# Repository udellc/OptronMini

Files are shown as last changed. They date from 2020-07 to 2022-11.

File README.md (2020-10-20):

# OptronMini
Repo for the Optron Mini

# Project Wiki:
https://github.com/udellc/OptronMini/wiki

# Folder Details
### BOM
Link to live spreadsheet of materials and links to products
### CAD
DXF: Laser Cutting File for Mini Frame
PCB: .sch and .brd files for Mini Circuit board
STL: 3D printer files
Archive: Old file dump for your enjoyment
### Code
Arduino code to download onto your Adafruit ItsyBitsy M4
### MaxMSP
Max8 apps tto use your Optron Mini!

# Getting Started
Please visit the Optron Project Wiki for setting up your Optron Mini!

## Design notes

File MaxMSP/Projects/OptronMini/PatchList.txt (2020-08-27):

--Input--
ModuleCore
GeneralViewer
Sensor
PositionVisualizer
SelectSD_Config
MidiIn
OSC_In
ArduinoIn
OptronMini
OptronZX
--Process--
ChordDegree
Concatenate
Movement
pH
RangeSetter
RotaryDial
ScaleCurve
ScaleLinear
Smooth
Threshold
ScaleDegree
Sequencer
Spring
TapTempo
--Output--
3Dpan
DMX
Draw
DrumKit
Lightsaber
MidiOut
Musicbox
OptronBOW
OptronCnfti
OptronFire
OptronGlitter
OptronHSV
OptronMouth
OptronPpit
OptronRGBSprite
OptronSpit
OSC_Out
SimpleSamp
Switchblade
--OutDevice--
Neopixel
Relay
Servo
Stepper
SetInterval

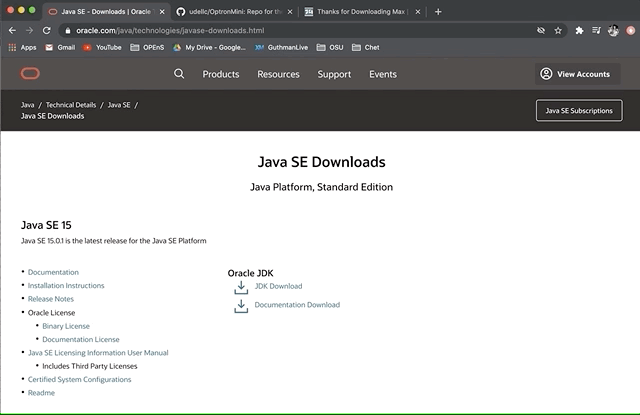
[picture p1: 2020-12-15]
05.jdk.gif

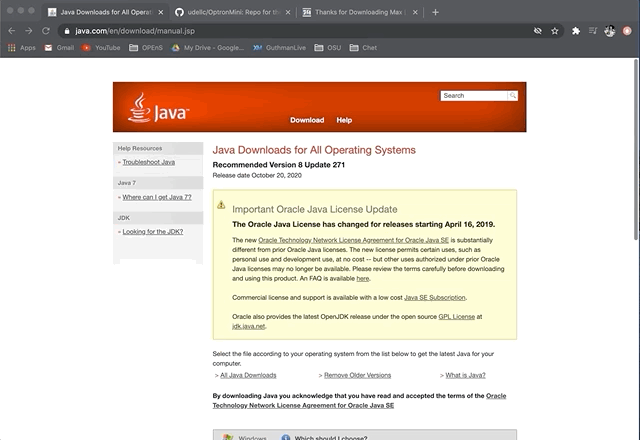
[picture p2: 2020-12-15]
03.java.gif

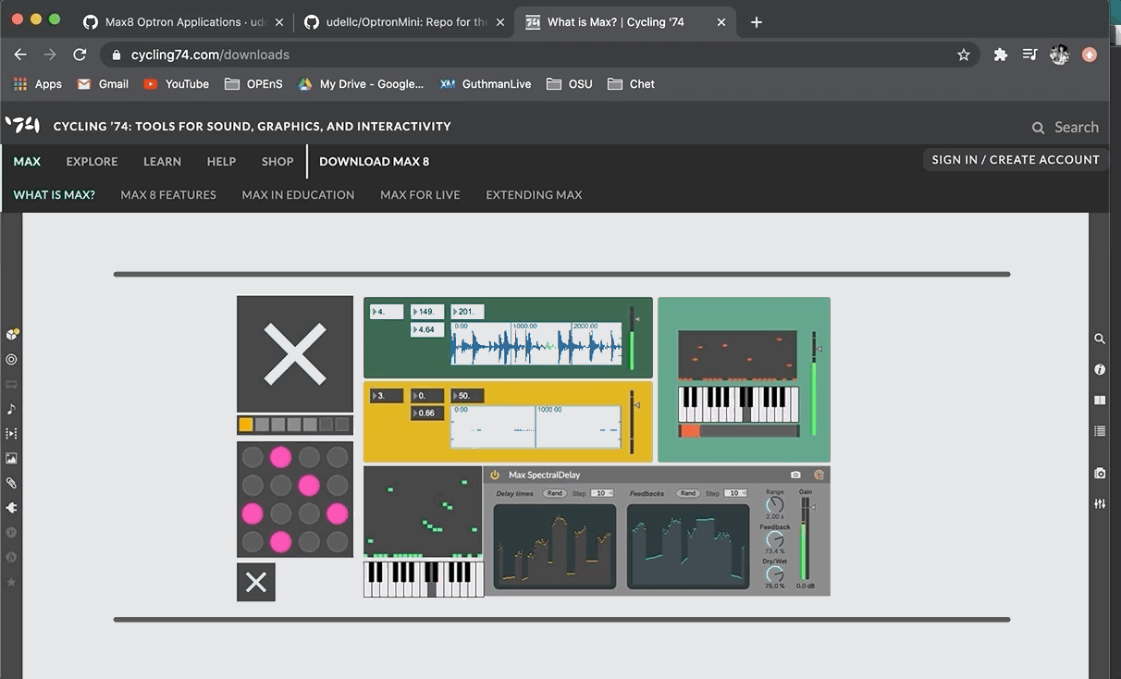
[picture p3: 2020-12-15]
00.DownloadMzx.gif

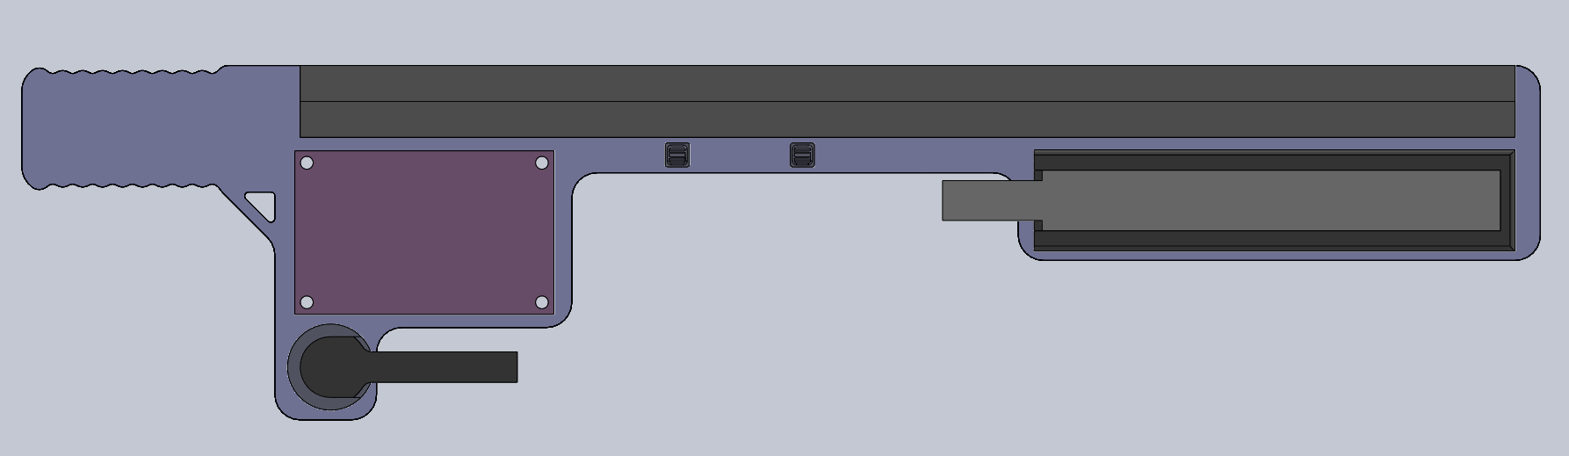
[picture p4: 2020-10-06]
CAD/pic_2.png

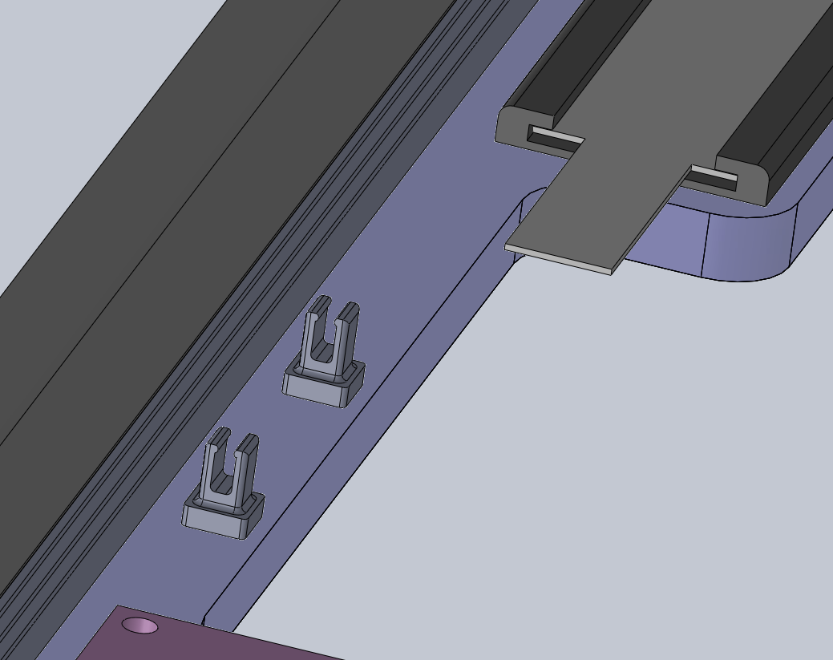
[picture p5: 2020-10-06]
CAD/pic_1.png

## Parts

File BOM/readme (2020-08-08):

See Live BOM here:
https://docs.google.com/spreadsheets/d/1z-zm15WeBKIYE_WQVqMh8_8pdPw357R4t1jwvQEjIIY/edit#gid=463961037

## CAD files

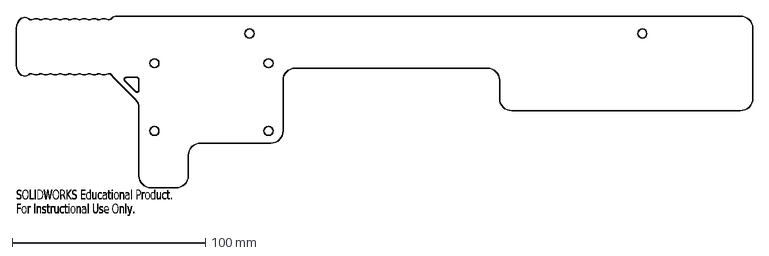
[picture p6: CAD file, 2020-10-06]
CAD/DXF/Optron_mini_mounting_plate_V2-1.DXF
SOLIDWORKS Educational Product.
For Instructional Use Only.

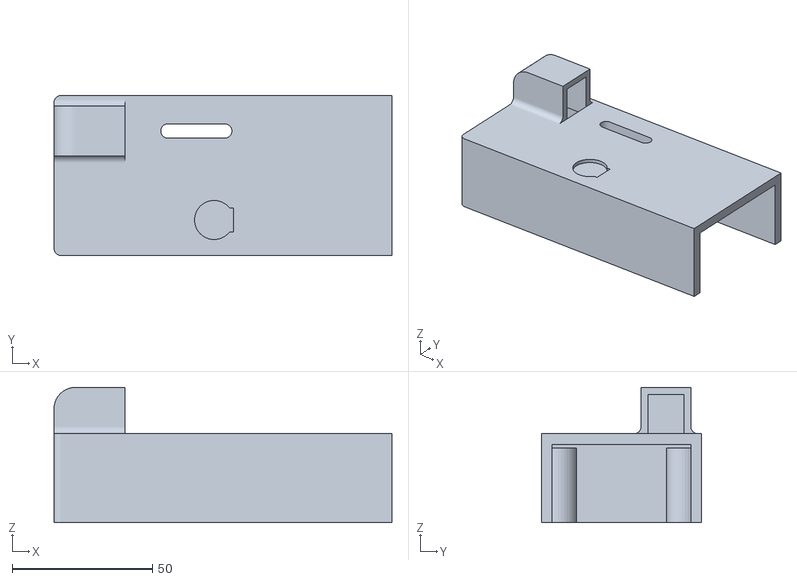
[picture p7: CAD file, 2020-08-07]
cad/mini_optron/Front_plate_a.STL
120.6 x 57.1 x 48.3

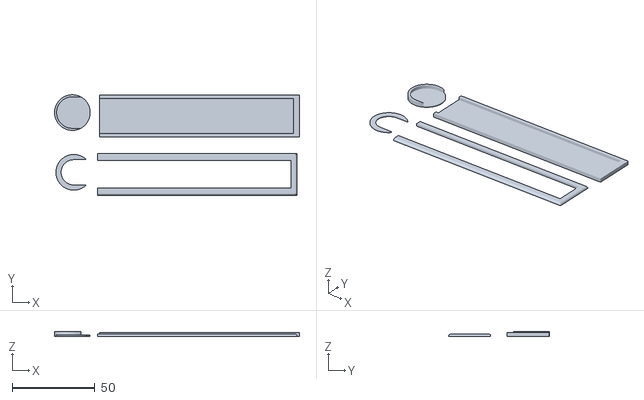
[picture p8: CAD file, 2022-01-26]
CAD/STL/OptMiniSet.stl
148.0 x 60.8 x 2.78

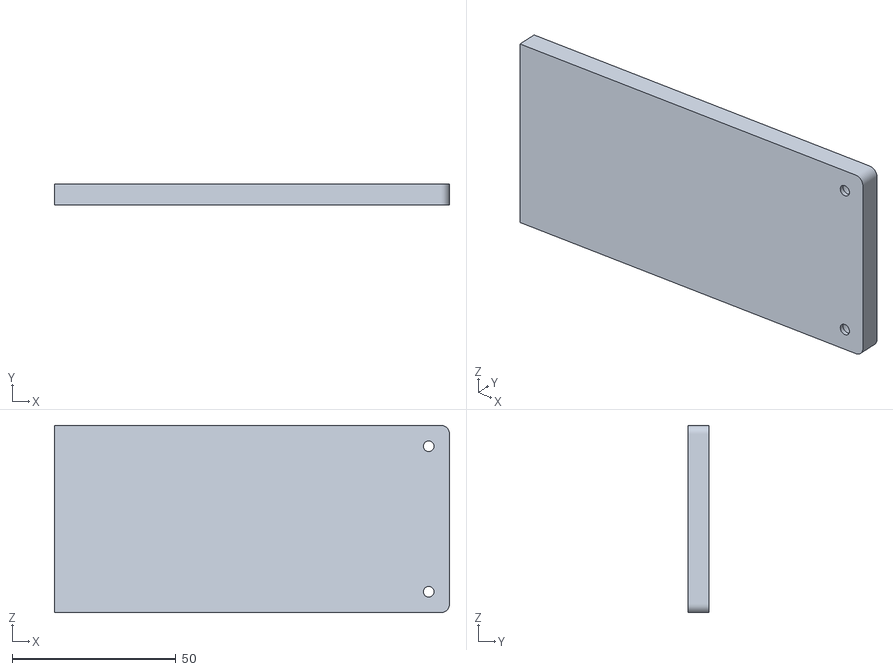
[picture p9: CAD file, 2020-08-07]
cad/mini_optron/Back_cover_a.STL
120.6 x 6.35 x 57.1

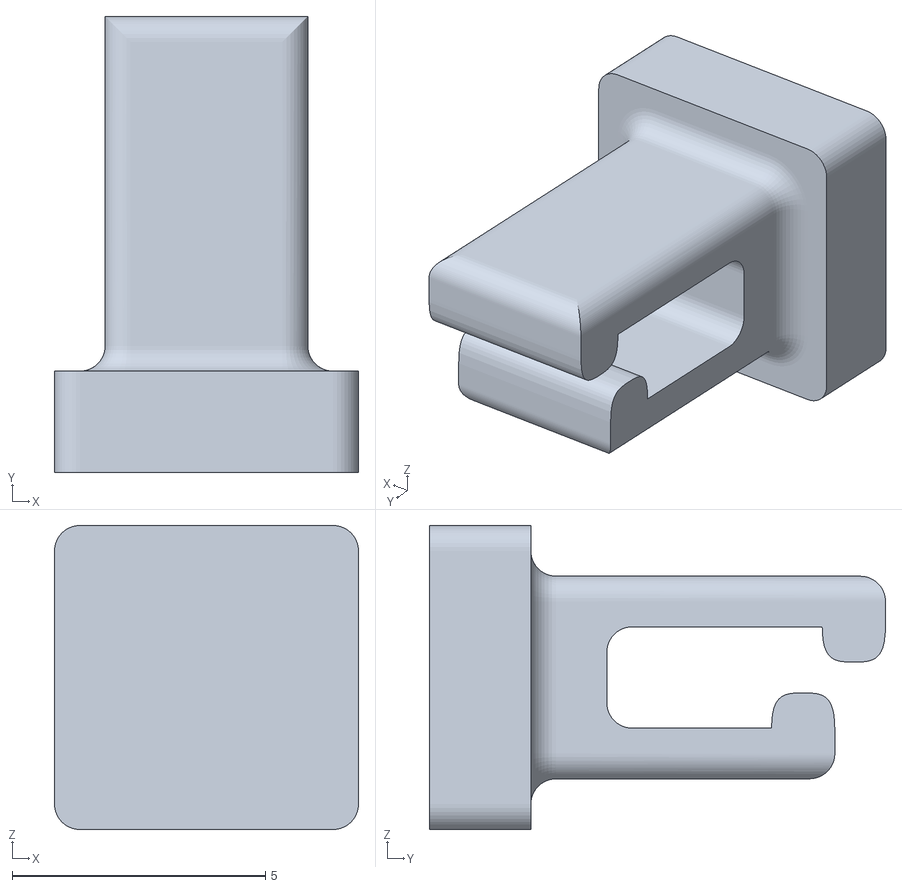
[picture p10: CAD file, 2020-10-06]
CAD/STL/Wire_holder_V3.STL
6.00 x 9.00 x 6.00

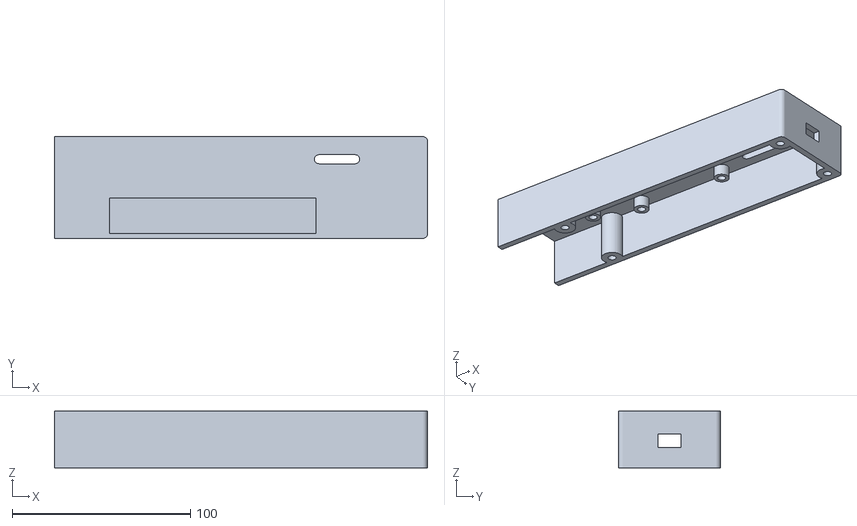
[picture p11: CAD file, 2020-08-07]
cad/mini_optron/Front_plate_b.STL
209.5 x 57.1 x 31.8

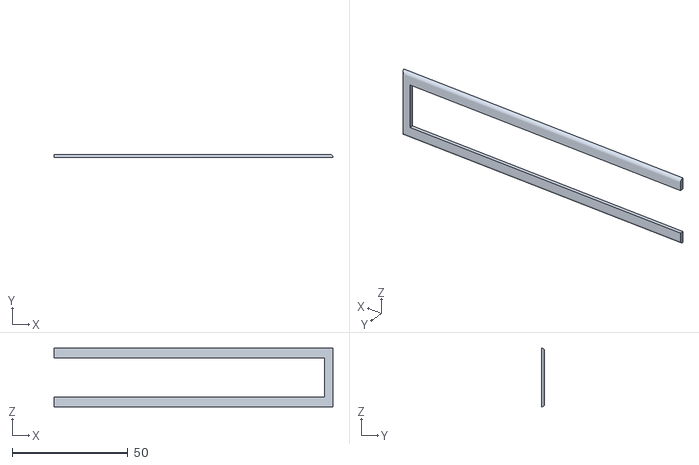
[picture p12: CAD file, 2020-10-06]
CAD/STL/Linear_pot_holder_top_V3.STL
120.7 x 1.40 x 25.4

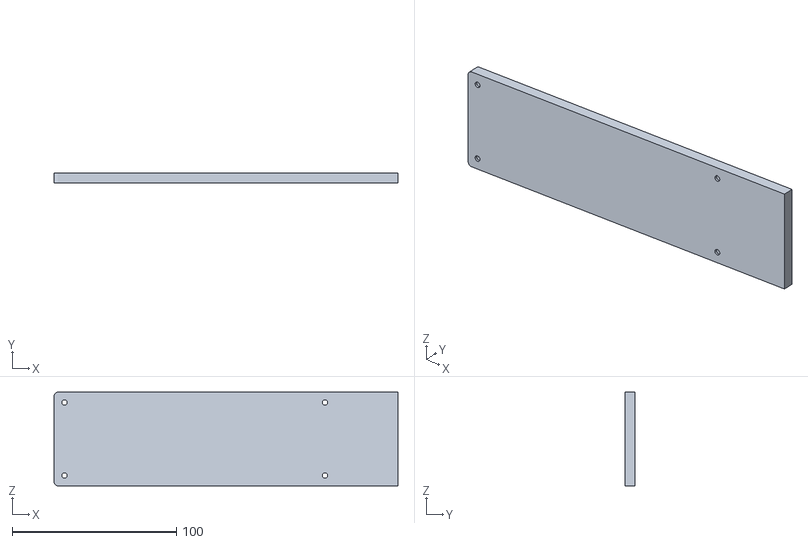
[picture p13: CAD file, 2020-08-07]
cad/mini_optron/Back_cover_b.STL
209.5 x 6.35 x 57.1

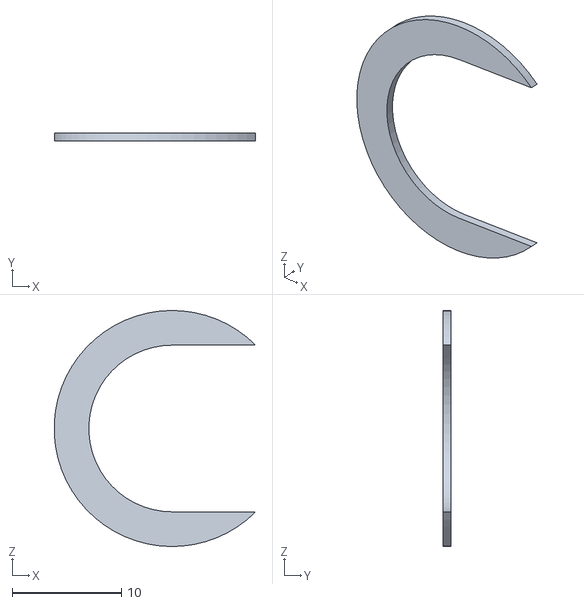
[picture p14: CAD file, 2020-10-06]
CAD/STL/force_sensor_holder_top_V3.STL
18.4 x 0.762 x 21.6

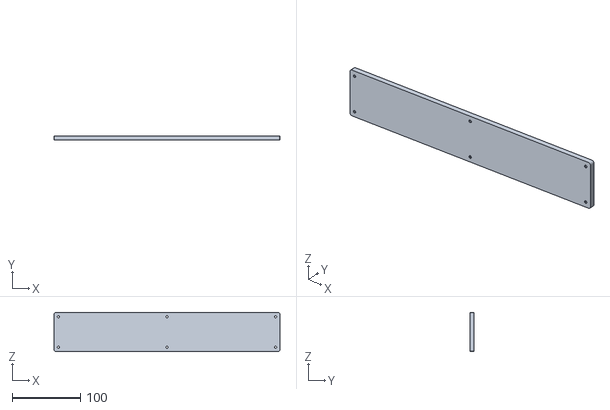
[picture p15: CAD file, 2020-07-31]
cad/mini_optron/Back_cover.STL
330.2 x 6.35 x 57.1

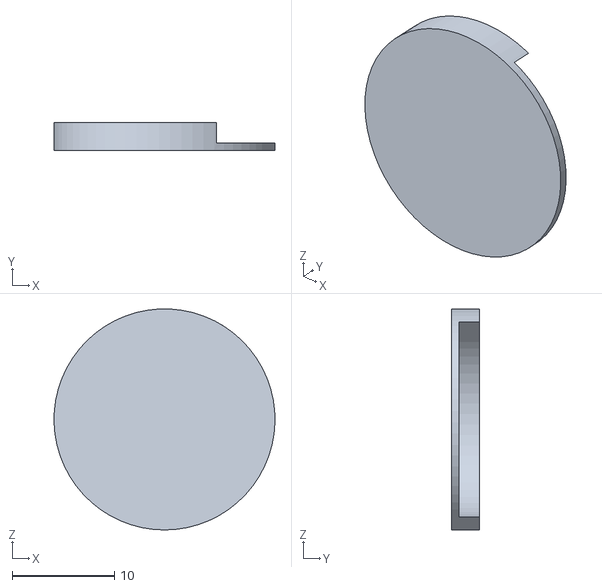
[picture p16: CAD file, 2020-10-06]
CAD/STL/force_sensor_holder_bottom_V3.STL
21.6 x 2.78 x 21.6

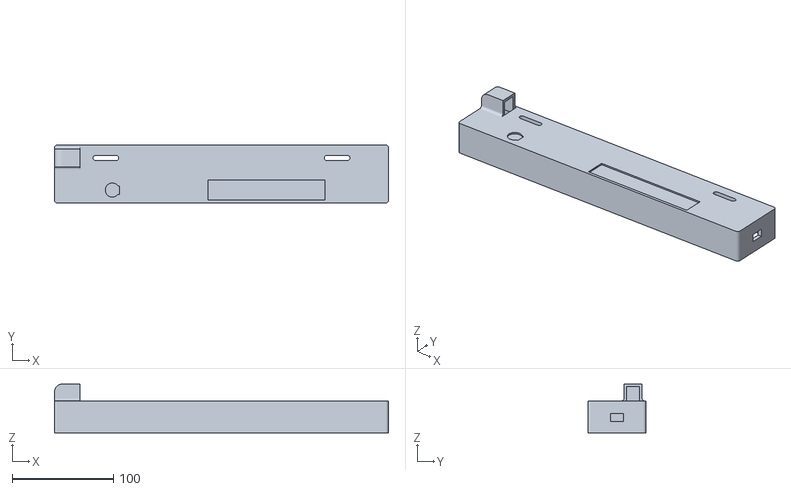
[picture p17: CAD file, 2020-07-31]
cad/mini_optron/Front_plate.STL
330.2 x 57.1 x 48.3

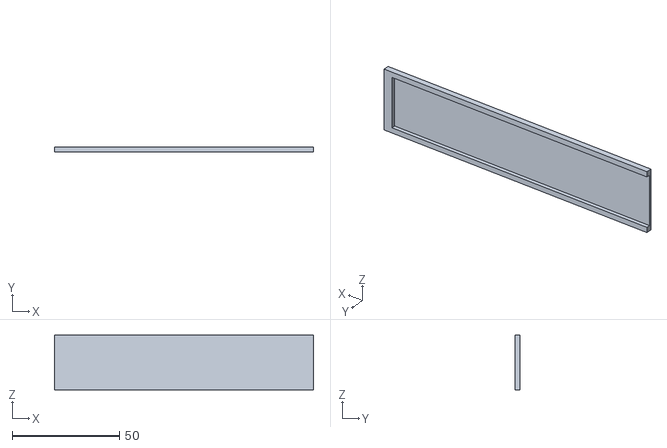
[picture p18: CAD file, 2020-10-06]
CAD/STL/Linear_pot_holder_bottom_V3.STL
120.7 x 2.41 x 25.4

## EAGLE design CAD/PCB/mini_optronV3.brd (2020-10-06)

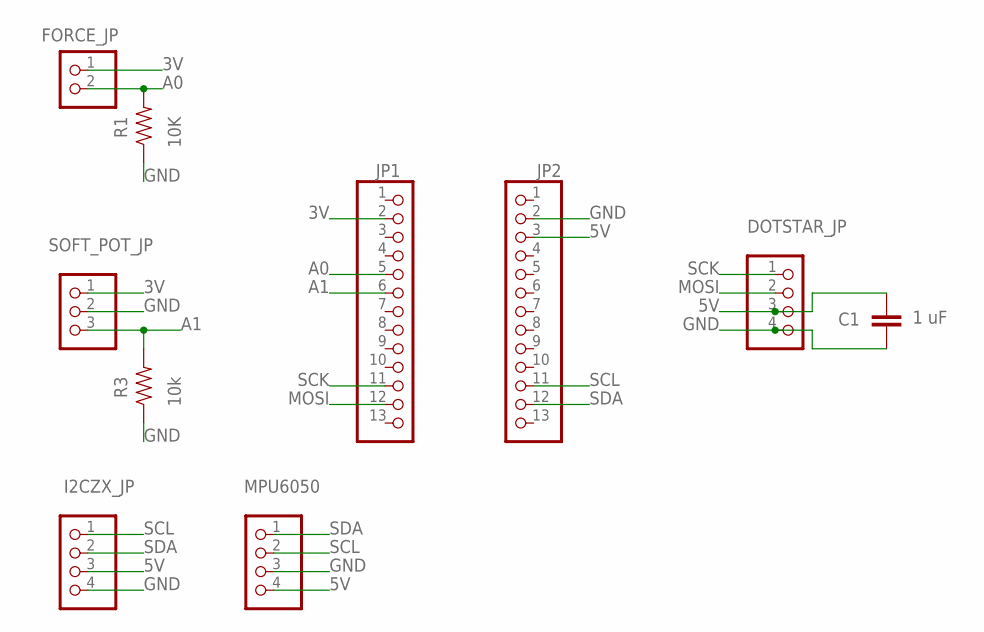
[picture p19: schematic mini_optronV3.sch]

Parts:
C1: 1 uF; C5B7.2; MPN 0805YD105KAT2A
DOTSTAR_JP: PINHD-1X4; 1X04
FORCE_JP: PINHD-1X2; 1X02
I2CZX_JP: PINHD-1X4; 1X04
JP1, JP2: PINHD-1X13_BIG; 1X13-BIG
MPU6050: PINHD-1X4; 1X04
R1: 10K; AXIAL-0.3; MPN CRCW060310K0FKEA
R3: 10k; AXIAL-0.3; MPN CRCW060310K0FKEA
SOFT_POT_JP: PINHD-1X3; 1X03

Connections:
3V: FORCE_JP.1, JP1.2, SOFT_POT_JP.1
5V: C1.1, DOTSTAR_JP.3, I2CZX_JP.3, JP2.3, MPU6050.4
A0: FORCE_JP.2, JP1.5, R1.P$2 (2)
A1: JP1.6, R3.P$2 (2), SOFT_POT_JP.3
GND: C1.2, DOTSTAR_JP.4, I2CZX_JP.4, JP2.2, MPU6050.3, R1.P$1 (1), R3.P$1 (1), SOFT_POT_JP.2
MOSI: DOTSTAR_JP.2, JP1.12
SCK: DOTSTAR_JP.1, JP1.11
SCL: I2CZX_JP.1, JP2.11, MPU6050.2
SDA: I2CZX_JP.2, JP2.12, MPU6050.1

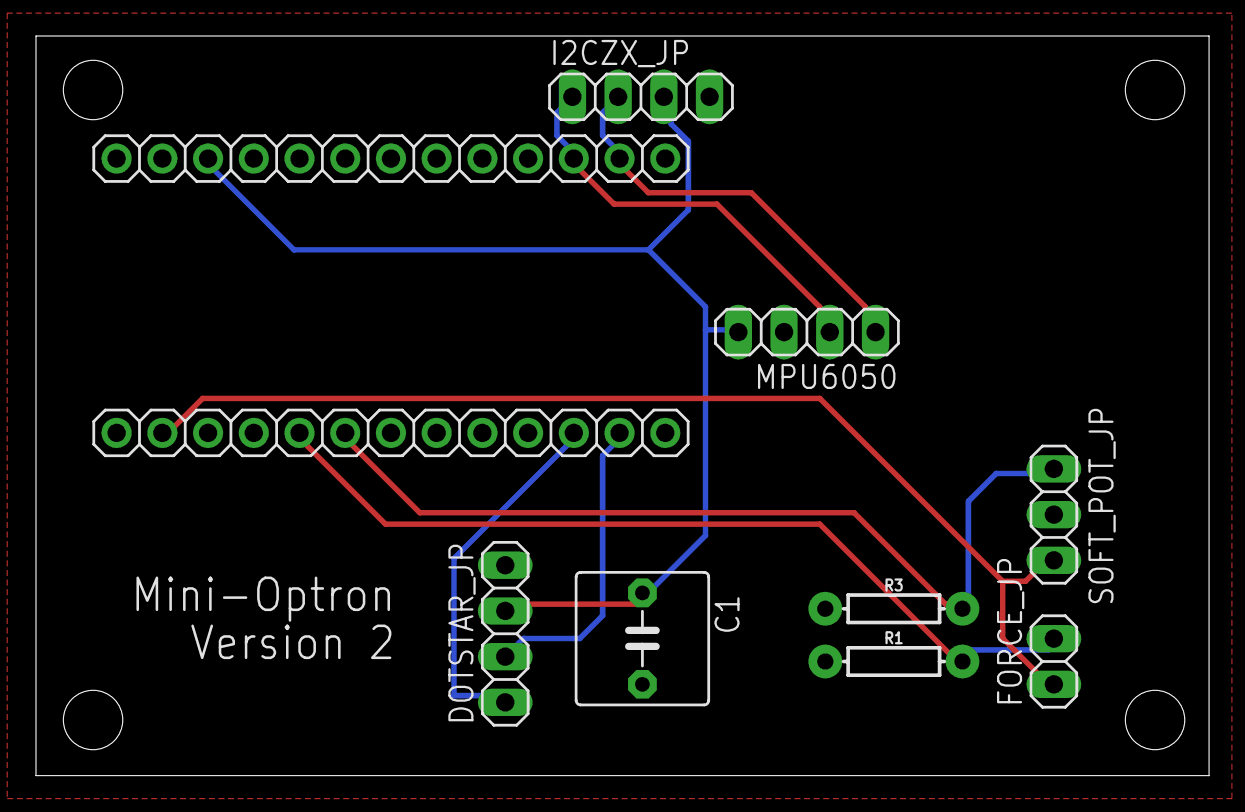
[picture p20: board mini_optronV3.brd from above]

Board: 2 copper layers, 65.2 x 41.1 mm, 10 parts (0 on the bottom side), 9 nets.

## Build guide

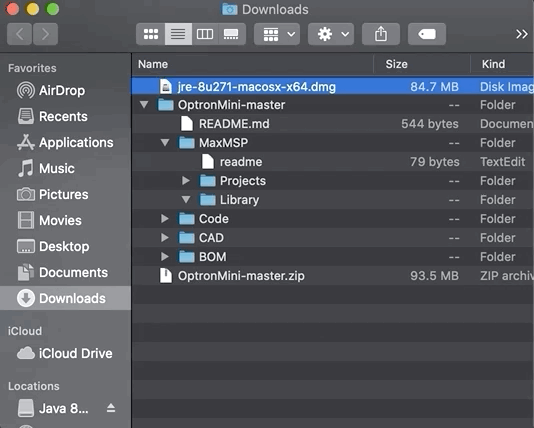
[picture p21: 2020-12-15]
04.javainstall.gif

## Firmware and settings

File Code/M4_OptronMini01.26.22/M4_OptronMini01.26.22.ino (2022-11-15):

// Arduino IDE 1.8.7
// SAMD boards 1.5.0
// FASTLED 3.002.006
// Dotstar Includes:
#include <Arduino.h>
#include <AsyncDelay.h>

#include <FastLED.h>

#define PlayerNum 1

FASTLED_USING_NAMESPACE

// FastLED "100-lines-of-code" demo reel, showing just a few 
// of the kinds of animation patterns you can quickly and easily 
// compose using FastLED.  
//
// This example also shows one easy way to define multiple 
// animations patterns and have them automatically rotate.
//
// -Mark Kriegsman, December 2014

#define LED_TYPE    SK9822
#define COLOR_ORDER BGR
#define NUM_LEDS    48
CRGB leds[NUM_LEDS];        // Place for final LED buffer at end of each cycle
CRGB LED_BUFFER[NUM_LEDS];      // volatile LED buffer for pushing/poping
CRGB spitOverlay[NUM_LEDS];  // color spit buffer
CRGB ppitOverlay[NUM_LEDS];  // color spit buffer
CRGB tickOverlay[NUM_LEDS]; // Create tick overlay
CRGB drumKitOverlay[NUM_LEDS];  // Drumkit sprite buffer
CRGB ARGBOverlay[NUM_LEDS];  // ARGB sprite buffer
CRGB funfettiOverlay[NUM_LEDS];  // FunFetti buffer
CRGB bellOverlay[NUM_LEDS];  // Drumkit sprite buffer

// colored dots that pulse for drums
CRGBPalette16 drumPalette = RainbowColors_p; // Choose a color palette
// colored dots that glow for bells
CRGBPalette16 bellPalette = ForestColors_p; // Choose a color palette
// Support vars for Fire effect
CRGBPalette16 gPal; // https://github.com/FastLED/FastLED/wiki/Gradient-color-palettes

#define BRIGHTNESS          200
#define FRAMES_PER_SECOND  120
//#define FRAMES_PER_SECOND  240
#define ARRAY_SIZE(A) (sizeof(A) / sizeof((A)[0]))

// List of patterns to cycle through.  Each is defined as a separate function below.
// The order in which you declare things is the order of layering from bottom to top
// first in is written first to the strip
typedef void (*SimplePatternList[])();
SimplePatternList gPatterns = { BGi, HSv, rainbow, ppit, spit, ticks, drumKit, ARGB, fairyFire, funfetti, bell, mouth, addGlitter };

bool patternEnArray[ARRAY_SIZE( gPatterns)] = {0}; // Create an enable array of same size as pattern array to enable/dissable pattern layers

uint8_t gCurrentPatternNumber = 0; // Index number of which pattern is current
uint8_t gHue = 0; // rotating "base color" used by many of the patterns

// LED Function Parameter Arrays (see LEDPatterns tab for functions and param descriptions)
uint8_t BGiParams[] = {0, 0, 0, 0, NUM_LEDS}; // R, G, B, LED_start, len
uint8_t HSVParams[] = {0, 0, 0, 0, NUM_LEDS}; // H, S, V, LED_start, len
uint8_t BOWParams[] = {0, NUM_LEDS, 5, 0};  // Start, len, hue Delta
uint8_t PPTParams[] = {0, 0, 0, 0, NUM_LEDS, 10}; // H, S, V, LED_start, len, fade_rate
uint8_t SPTParams[] = {0, 0, 0, 0, NUM_LEDS, 10}; // H, S, V, LED_start, len, fade_rate
uint8_t FIRParams[] = {0, 0, 0, 0, NUM_LEDS, 254}; // Hue, Sparking, Cooling, LED_start, len, fade
uint8_t DKTParams[] = {0}; // on/off
uint8_t ARGBParams[] = {1, 1, 1, 2, 2, 2, 3, 3, 3, 30}; // indexR, wideR, brightR, indexG, wideG, brightG,indexB, wideB, brightB, fade_rate
uint8_t TCKParams[] = {4, 0, 0, 0, 127, 20}; // density, direction, hue, saturation, volume, tickSteps
uint8_t CFIParams[] = {0, 0, 0, 0, 169, 255}; // (on/off) h, s, v, start, len, density
uint8_t MOUParams[] = {0, 0, 0, 2, 1, 169}; // on/off h, s, v, start, len
uint8_t GLRParams[] = {40, 0, 127, 0, 2}; // h, s, v, randColorSpread, density

uint8_t RGBHSV[] = {0, 96, 160}; //hue translation for RGB
uint8_t glitterForce = 0; // intensity of Glitter
uint8_t glitterPos = -1; // Place glitter randomly lights up to report back to MaxMSP

// left-of-center Positions of ZX sensors relative to DotStar strip LED positions for visualization
uint8_t ZXSensorPos[] = {10, 31, 52, 73, 94, 115, 136, 157};

//==========================================================
// Sensor Includes:
//==========================================================
    #include "Wire.h"
    #include <ZX_Sensor.h>
    #include <SPI.h>


// uncoment one of these - which format do we want stuff output on serial?
#define OUTPUT_BINARY
//#define OUTPUT_READABLE

unsigned long previousMillis = 0; // will store last time samples were sent
const long interval = 10;  // interval at which to send samples (milliseconds)

const int MPU_ADDR = 0x68; // also define i2c address of MPU

#include "I2Cdev.h"
#include "MPU6050.h"
// Arduino Wire library is required if I2Cdev I2CDEV_ARDUINO_WIRE implementation
// is used in I2Cdev.h
#if I2CDEV_IMPLEMENTATION == I2CDEV_ARDUINO_WIRE
    #include "Wire.h"
#endif

  MPU6050 accelgyro; // another called accelgyro
#define INTERRUPT_PIN 11  // use pin 11 on Micro, use pin 2 on Arduino Uno & most boards
// MPU control/status vars
bool dmpReady = false;  // set true if DMP init was successful
uint8_t mpuIntStatus;   // holds actual interrupt status byte from MPU
uint8_t devStatus;      // return status after each device operation (0 = success, !0 = error)
uint16_t packetSize;    // expected DMP packet size (default is 42 bytes)
uint16_t fifoCount;     // count of all bytes currently in FIFO
uint8_t fifoBuffer[64]; // FIFO storage buffer


// Place to save accel gyro mpu6050 readings
int16_t ax, ay, az;
int16_t gx, gy, gz;

// MPU calibration vars:
int mean_ax,mean_ay,mean_az,mean_gx,mean_gy,mean_gz,state=0;
//int ax_offset,ay_offset,az_offset,gx_offset,gy_offset,gz_offset;
//Change this 3 variables if you want to fine tune the skecth to your needs.
int buffersize=1000;     //Amount of readings used to average, make it higher to get more precision but sketch will be slower  (default:1000)
int acel_deadzone=8;     //Acelerometer error allowed, make it lower to get more precision, but sketch may not converge  (default:8)
int giro_deadzone=1;     //Giro error allowed, make it lower to get more precision, but sketch may not converge  (default:1)

// ================================================================
// ===               INTERRUPT DETECTION ROUTINE                ===
// ================================================================

volatile bool mpuInterrupt = false;     // indicates whether MPU interrupt pin has gone high
void dmpDataReady() {
    mpuInterrupt = true;
}


// Sparkfun XZ Sensor stuff:
//#define TCAADDR 0x71

// Constants
const int ZX_ADDR = 0x10;  // ZX Sensor I2C address

// Global Variables
ZX_Sensor zx_sensor = ZX_Sensor(ZX_ADDR);
uint8_t x_pos = 255;
uint8_t z_pos = 255;

/*
// --- TCASESELECT --- 
//
// Set port to begin reading from
// 
// @param port_num  Port to read from
//
void tcaseselect(uint8_t port_num) 
{
  if (port_num < 8) {
    Wire.beginTransmission(TCAADDR);
    Wire.write(1 << port_num);
    Wire.endTransmission();  
  }
}
*/

// Analog Sensor Inputs
const int FSRPin = A0;  // Analog input pin that the FSR is attached to, using long FSR, and 10Kohm voltage divider
const int LinPin = A1;  // Analog input pin that the Line Pot is attached
const int IRPin = A2;  // Analog input pin IR Distance sensor is attached
//const int ePicDownPin = A3;  // Analog input pin that the ePic other direction is attached

int fsrVal = 0; // Place to store FSR val
int linVal = 0; // Place to store LinPot val
int irVal = 0; // Place to store FSR val
//int ePicDownVal = 0; // Place to store LinPot val


// ================================================================
// ===           Convert float to binary ROUTINE                ===
// ================================================================
typedef union {
 float floatingPoint;
 byte binary[4];
} binaryFloat;


void setup() {
  Serial.begin(230400); // Initialize serial port 
  delay(3000); // 3 second delay for recovery
  
  // tell FastLED about the LED strip configuration
  FastLED.addLeds<LED_TYPE,COLOR_ORDER>(leds, NUM_LEDS).setCorrection(TypicalLEDStrip);
  //FastLED.addLeds<LED_TYPE,DATA_PIN,CLK_PIN,COLOR_ORDER>(leds, NUM_LEDS).setCorrection(TypicalLEDStrip);

  // set master brightness control
  FastLED.setBrightness(BRIGHTNESS);

  //==========================================================
// Sensors Setup:
//==========================================================
  // join I2C bus (I2Cdev library doesn't do this automatically)
    #if I2CDEV_IMPLEMENTATION == I2CDEV_ARDUINO_WIRE
        Wire.begin();
    #elif I2CDEV_IMPLEMENTATION == I2CDEV_BUILTIN_FASTWIRE
        Fastwire::setup(400, true);
    #endif

// ZX Init
    Wire.beginTransmission(ZX_ADDR);
      byte error = Wire.endTransmission();
      if (error == 0)
      {
         #ifdef OUTPUT_READABLE
         Serial.println("Found ZX Sensor!");
         #endif
         zx_sensor.init();
      }

  analogReadResolution(12); // 12 bit analog
  delay(5000);

  // *** Init MPU 6050 and serial stuff
  pinMode(INTERRUPT_PIN, INPUT);
#ifdef OUTPUT_READABLE
  Serial.println("Setting up MPU6050 raw");
#endif
  accelgyro.initialize();

    accelgyro.setZAccelOffset(1000); // 1688 factory default for my test chip
    accelgyro.setXGyroOffset(140); // was 220, 120=-.25, 180=.56, 150=.19, 135=-.06, 140=0
    accelgyro.setYGyroOffset(-10); // 76 = 1.192, 100=1.5, 50=0.8, 20=.35, -20=-.15, -10=0
    accelgyro.setZGyroOffset(60); //-75=-1.9, -20=-1., 20=-.5, 40=-.2, 60=.0
    

/*  
  #ifdef OUTPUT_READABLE
  Serial.println("Scanning for i2c MUXed devices...");
  #endif
  for (uint8_t t=0; t<8; t++) {
    delay(100);
      tcaseselect(t);
      #ifdef OUTPUT_READABLE
      Serial.print("TCA Port #"); Serial.println(t);
      #endif
      Wire.beginTransmission(ZX_ADDR);
      byte error = Wire.endTransmission();
      if (error == 0)
      {
         #ifdef OUTPUT_READABLE
         Serial.println("Found ZX Sensor on this port!");
         #endif
         zx_sensor.init();
      }
          
    }
        #ifdef OUTPUT_READABLE
        Serial.println("\ndone");
        #endif
*/     
  
  // Enable Rainbow Pattern On Startup: 
        patternEnArray[2] = 1;  // Rainbow On
        BOWParams[0] = 2;  // hue delta (length of hue transitions)
        BOWParams[1] = 0;   // Start LED
        BOWParams[2] = NUM_LEDS-1;   // Len
        BOWParams[3] = 200;   // Fade ammount, 0 strong to 255 weak

        clipLen(&BOWParams[1],&BOWParams[2]);
  delay(1000);
}


void loop()
{

  querySerial();

  callPatterns();

//==========================================================
// Sensor Stuff
//==========================================================

 // Check to see if it's time to send sensor vals
  unsigned long currentMillis = millis();
   if (currentMillis - previousMillis >= interval) {
    //Serial.print("Time: ");
    //Serial.println(currentMillis);
    // save the last time you sent vals
    previousMillis = currentMillis;
    
    // clear MPU fifo
    accelgyro.resetFIFO(); 
    
    // Read Sparkfun XZ sensor and report vals
    readXZ();

    // Read Analog Sensor Vals
    readAnalog();

    // Now measure MPU6050, update values in global registers
    measure_mpu6050();
    
    // Send new data out to Serial (either binary or human redable specified up top
    sendVals();

   }

}

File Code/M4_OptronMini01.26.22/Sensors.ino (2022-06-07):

void sendVals()
{
  #ifdef OUTPUT_READABLE

      Serial.print("Player Number: "); Serial.println(PlayerNum);

      
      Serial.println("MPU6050");
//      Serial.println((float)yaw);
//      Serial.println((float)pitch);
//      Serial.println((float)roll);
      Serial.println((float)ax/16000);
      Serial.println((float)ay/16000);
      Serial.println((float)az/16000);
      Serial.println((float)gx/16000);
      Serial.println((float)gy/16000);
      Serial.println((float)gz/16000);

 
// print all ZX values
      if ( z_pos != ZX_ERROR ) 
      {
        Serial.print("Z: "); 
        Serial.print(z_pos);
      }
      if ( x_pos != ZX_ERROR ) 
      {
        Serial.print("  X: "); 
        Serial.println(x_pos);
      }
        
      Serial.print(" FSR: ");
      Serial.println(fsrVal);

      Serial.print(" LinPot: ");
      Serial.println(linVal);
      
    #endif
    
    #ifdef OUTPUT_BINARY
      // Sensor number (1=analog, 2=MPU, 3=SpkZX, 4=player ), num packets
      // sensor1 H, Sensor1 L
      // sensor2 H, Sensor1 2
      // etc
      // packet data
      binaryFloat hi;
// Note, the first two bytes transmitted must be taken into account in the software serial client
// byte 1 = device type, byte 2 = how many transactions/transmits
// Type 1 = analog sensor transmitting 2-byte (H/L) ints, Type 2 = serial, 4-byte floating point

// 4 = device type player, 1-byte unsigned, then transmit 1 transaction of this type
     //Serial.write((uint8_t)2); Serial.write((uint8_t)9); // Use this for transmitting all 9 things (YPR)
     Serial.write((uint8_t)4); Serial.write((uint8_t)1); // Without YPR transmission
      // ex: 0, 1, a, etc . . .
     // FSR high byte, low byte
     Serial.write((uint8_t)(PlayerNum));
     
     // 2 = device type serial, 4-byte floating point, then transmit 9 transactions of this type
     //Serial.write((uint8_t)2); Serial.write((uint8_t)9); // Use this for transmitting all 9 things (YPR)
     Serial.write((uint8_t)2); Serial.write((uint8_t)6); // Without YPR transmission
      // ex: 2, 9, a a a a, b b b b, c c c c, etc . . .
//      hi.floatingPoint = yaw; Serial.write(hi.binary,4);
//      hi.floatingPoint = pitch; Serial.write(hi.binary,4);
//      hi.floatingPoint = roll; Serial.write(hi.binary,4);
      hi.floatingPoint = (float)ax/16000; Serial.write(hi.binary,4);
      hi.floatingPoint = (float)ay/16000; Serial.write(hi.binary,4);
      hi.floatingPoint = (float)az/16000; Serial.write(hi.binary,4);
      hi.floatingPoint = (float)gx/16000; Serial.write(hi.binary,4);
      hi.floatingPoint = (float)gy/16000; Serial.write(hi.binary,4);
      hi.floatingPoint = (float)gz/16000; Serial.write(hi.binary,4);

      // 1 = type Analog, 2-byte int (H/L), transmit 4 transactions of this type
      Serial.write(1); Serial.write(3); // GLR + 3 analog
      // ex: 1, 4, a a, b b, c c, d d  (till finished)
      
      // IR sensor high byte, low byte
      //Serial.write((uint8_t)(irVal >> 8)); Serial.write((uint8_t)(irVal & 0xFF));

      // Optron Light Event Out high byte, low byte
      Serial.write((uint8_t)(0x00)); Serial.write((uint8_t)(glitterPos));
      
      // FSR high byte, low byte
      Serial.write((uint8_t)(fsrVal >> 8)); Serial.write((uint8_t)(fsrVal & 0xFF));
      
      // Linear sensor high byte, low byte
      Serial.write((uint8_t)(linVal >> 8)); Serial.write((uint8_t)(linVal & 0xFF));
      
      // ePicUp high byte, low byte
//      Serial.write((uint8_t)(ePicUpVal >> 8)); Serial.write((uint8_t)(ePicUpVal & 0xFF));

      // LinPot high byte, low byte
//      Serial.write((uint8_t)(ePicDownVal >> 8)); Serial.write((uint8_t)(ePicDownVal & 0xFF));
// Send ZX packet
      // 3 = type ZX, 2-byte int, transmit 2 transactions of this type
     Serial.write(3); Serial.write(2); // 2 ZX readings
      // ex: 3, 2, a a, b b
      
    // print all ZX values
      if ( (z_pos != ZX_ERROR) && (x_pos != ZX_ERROR))  // Send if ZX is connected
      {
      // print all ZX values
        Serial.write(z_pos);
        Serial.write(x_pos);
      }
      else
      {
        // if no updated value, 
        Serial.write(255); // Send max hand away
        Serial.write(x_pos); // and last known position of X
      }

     
  // ********** Get All Readings right!     ********  
    #endif
    
}

// SPARKFUN XZ Sensor Read Function:
void readXZ()
{
  // If there is position data available, read and print it
  if ( zx_sensor.positionAvailable() ) {
    x_pos = zx_sensor.readX();
    z_pos = zx_sensor.readZ();
  }
  /*
  // commented out because we want the last updated value sent per cycle even if sensors don't update this go around
  else{ 
      x_pos = x_pos;
      z_pos = 255;
    }
    */
}


// Read Analog sensor values
void readAnalog()
{
  fsrVal = analogRead(FSRPin);
  linVal = analogRead(LinPin);
//  irVal = analogRead(IRPin);
//  ePicDownVal = analogRead(ePicDownPin);
}

// Generic subroutine for reading MPU6050 i2c Data
void measure_mpu6050(void)
{
  // read raw accel/gyro measurements from device
    accelgyro.getMotion6(&ax, &ay, &az, &gx, &gy, &gz);

    // these methods (and a few others) are also available
    //accelgyro.getAcceleration(&ax, &ay, &az);
    //accelgyro.getRotation(&gx, &gy, &gz);


} // of measure_mpu6050() 

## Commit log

2020-05-07 Add files via upload
    Mini-optron schematic and board layout.
    [mini_optron.brd, mini_optron.sch]
2020-05-07 Updated FSR circuit, c1 orient
    [mini_optron.brd, mini_optron.sch]
2020-08-08 MaxPatches Sensors LEDs
2020-08-08 add BOM folder
2020-10-20 add libraries arduino
2022-01-26 upload arduino code
2022-06-07 Update LEDs and ZX sensor

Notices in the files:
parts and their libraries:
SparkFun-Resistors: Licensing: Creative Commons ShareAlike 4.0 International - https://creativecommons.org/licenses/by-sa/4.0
